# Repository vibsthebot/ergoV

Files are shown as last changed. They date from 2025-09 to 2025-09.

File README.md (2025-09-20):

# ergoV

Picture of Keyboard in Case

A custom ergonomic split keyboard powered by a nrf52840 and PG1316S switches. At under 8 millimeters thick, this keyboard is extremly thin and portable. 

## Features
* Battery Charging
* USB C
* Bluetooth

## PCB 
Image of PCB

## Schematic
Schematic Picture

Designed in [KiCAD](https://kicanvas.org/?github=https%3A%2F%2Fgithub.com%2Fvibsthebot%2FergoV%2Ftree%2Fmain%2Fsrc%2Fleft) and [Onshape](https://cad.onshape.com/documents/23d341e5ba1096076f5e498a/w/17b9fcd4bdbd13d07aada607/e/fd0f7eacd049861961437f33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)

## BOM

| Item | Quantity | Link | Price (each) |
|---|---|---|---|
| 301540 batteries | 2 | [AliExpress](https://www.aliexpress.com/i/2255800173650652.html) | $6.10 |
| PCB (JLCPCB) | 2 | - | $8.40 |
| LCSC parts | - | - | $50.00 |
| PG1316S switches (10 pack) | 4 packs  | [HolyKeebs](https://holykeebs.com/products/kailh-pg1316s-butterfly-switch-10-pack) | $7.50 |
| PG1316S keycaps (10 pack) | 4 packs  | [HolyKeebs](https://holykeebs.com/products/kailh-pg1316s-keycaps) | $4.50 |
| **Total** | | | **$129.60**  |

**Total estimated cost:** $129.60

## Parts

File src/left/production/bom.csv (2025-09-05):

Designator | Footprint | Quantity | Value | LCSC Part #
BT1 | JST_PH_S2B-PH-K_1x02_P2.00mm_Horizontal | 1 | Battery | C265016
C1, C22 | 0402 | 2 | 4.7uF | C1779
C11, C2, C3, C4 | 0402 | 4 | 10uF | C15525
D1, D10, D11, D12, D13, D14, D15, D16, D17, D18, D2, D25, D26, D27, D3, D4, D5, D6, D7, D8, D9 | Diode_SOD-123 | 21 | D | C81598
D28 | D_SOD-123 | 1 | MBR0540 | C77337
D29 | 0805 | 1 | Orange | C434437
J1 | USB_C_Receptacle_G-Switch_GT-USB-7010ASV | 1 | USB_C_Receptacle_USB2.0_16P | C67380
Q1 | SOT-23 | 1 | AO3401A | C306862
R1, R2 | 0402 | 2 | 27 | C25100
R11 | 0402 | 1 | 2k | C17604
R12 | 0402 | 1 | 0.47k | C17710
R3, R4 | 0402 | 2 | 5k1 | C25905
R7 | 0402 | 1 | 10k | C17414
SW1, SW10, SW11, SW12, SW13, SW14, SW15, SW16, SW17, SW18, SW2, SW25, SW26, SW27, SW3, SW4, SW5, SW6, SW7, SW8, SW9 | CPG1316S01D02_kailhspecsheet_mikefive | 21 | SW_Push_3pin_GND
U1 | Raytac_MDBT50Q | 1 | MDBT50Q-1MV2
U2 | SOT-23-5 | 1 | MCP73831-2-OT | C14879
U4 | SOT-23-6 | 1 | USBLC6-2SC6 | C5180249

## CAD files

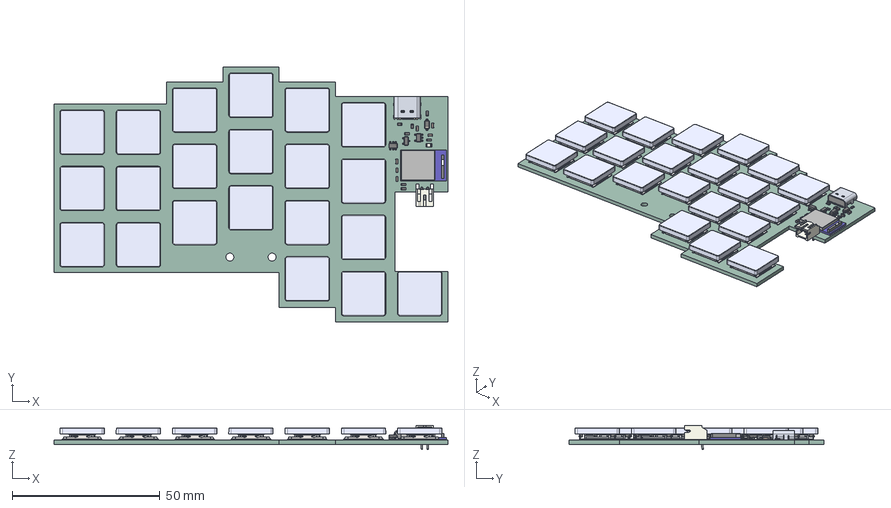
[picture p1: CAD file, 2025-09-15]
src/left/ergoV.step
133.4 x 86.2 x 8.25 mm
Diode_SOD-123 x 21
1316S-»ù×ù¿¨¼þ x 21
PG1316S-»ù×ù x 21
Ƚ¶¯¸ x 21
ƽº⽜ x 21
-» x 21
PG1316S-¶¯½Ó´¥Æ¬-´ø´¥µã x 21
PG1316S-¾²Æ¬-´ø´¥µã x 21
ƽº⽜-B x 21
¼üÃ± x 21
C_0603_1608Metric x 6
USB Type C Port (SMD Type)
R_0603_1608Metric x 7
JST_PH_S2B-PH-K_1x02_P2.00mm_Horizontal
SOT-23-5
D_SOD-123
Raytac_MDBT50Q
SOT-23-6
SOT-23
LED_0805_2012Metric
ergoV_PCB

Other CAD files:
src/right/ergoVright.step

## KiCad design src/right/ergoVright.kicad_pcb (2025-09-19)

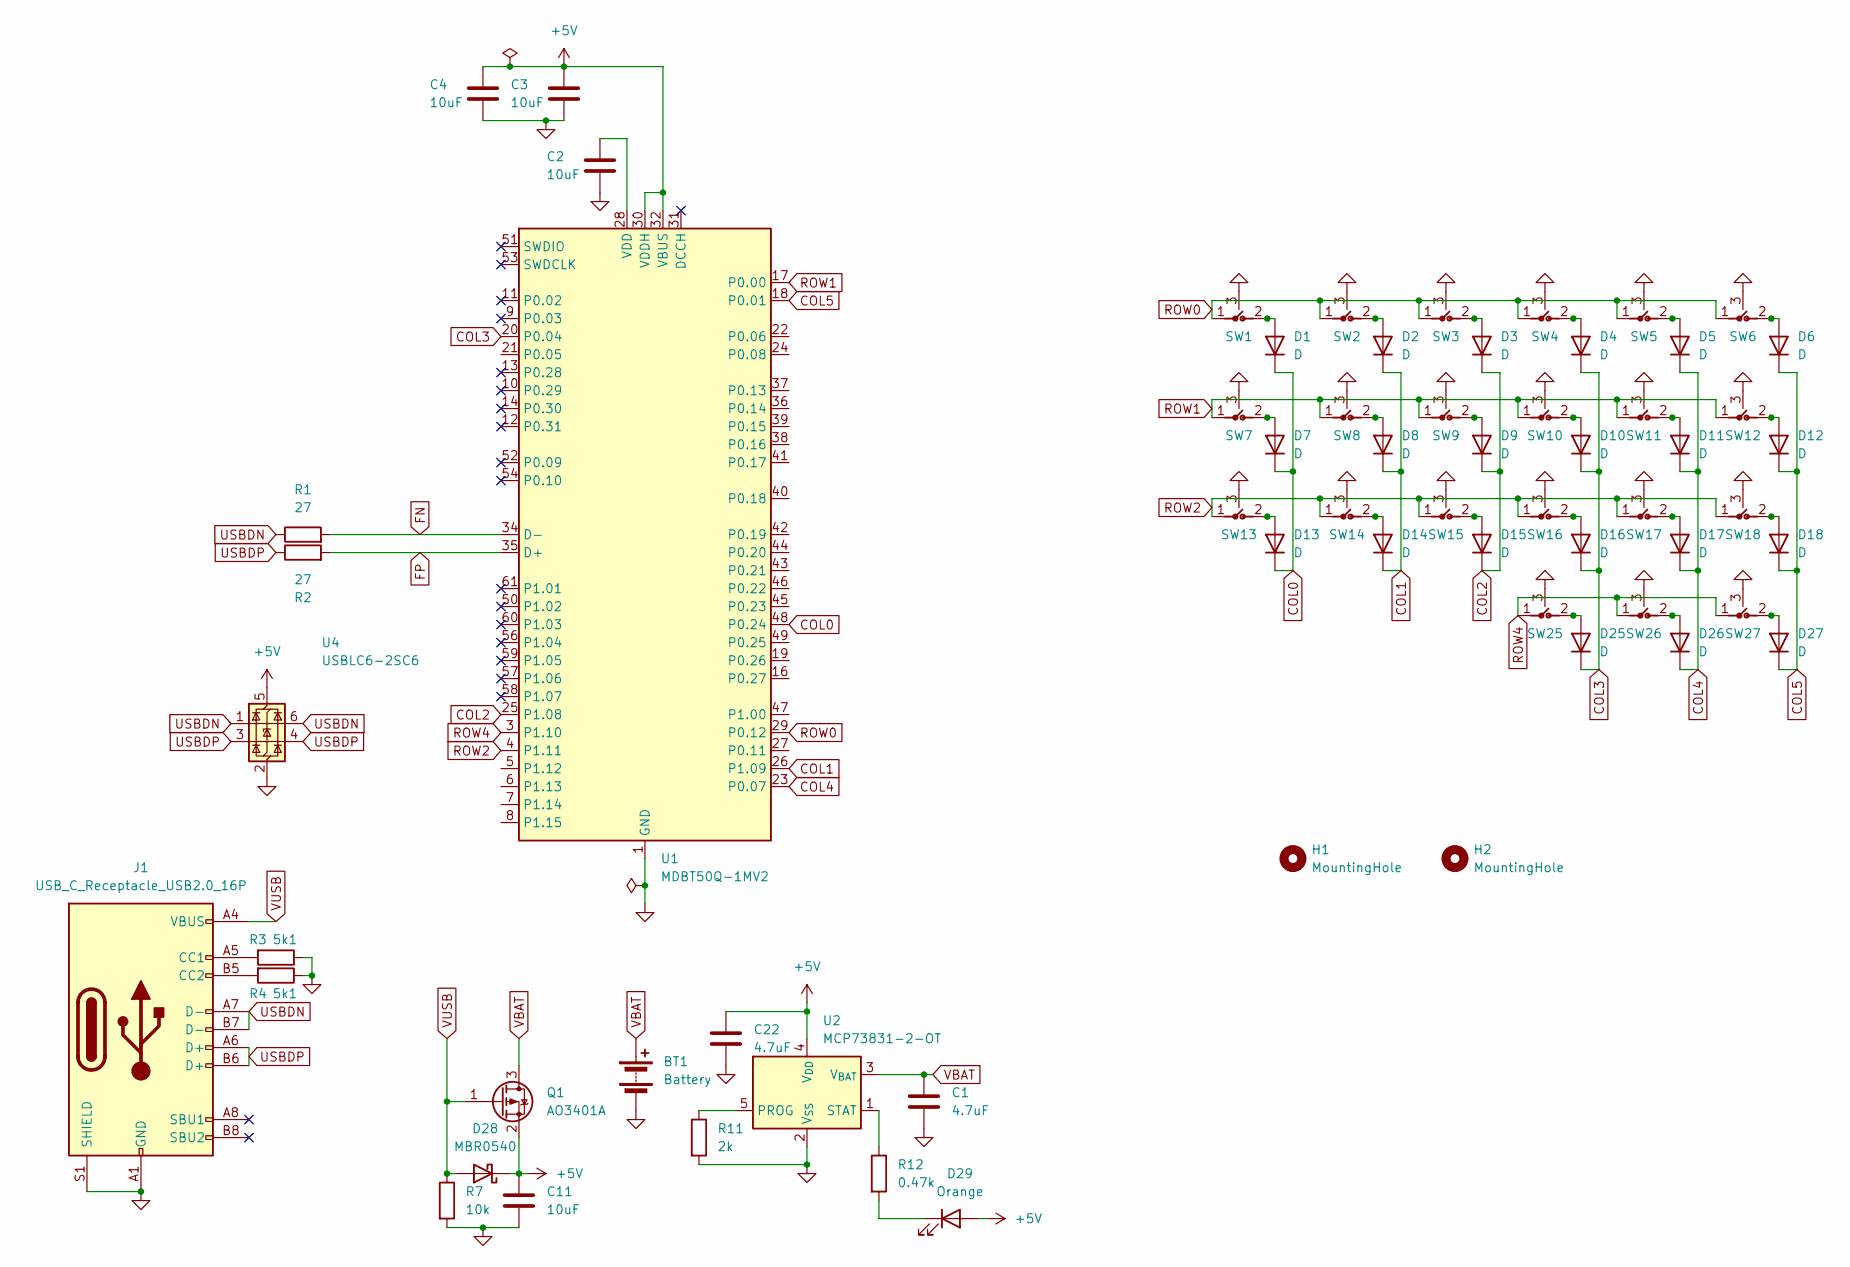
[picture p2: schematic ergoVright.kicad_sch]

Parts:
BT1: Battery; JST_PH_S2B-PH-K_1x02_P2.00mm_Horizontal
C1, C22: 4.7uF; C_0603_1608Metric; LCSC C19666
C2, C3, C4, C11: 10uF; C_0603_1608Metric; LCSC C19702
D1, D2, D3, D4, D5, D6, D7, D8, D9, D10, D11, D12, D13, D14, D15, D16, D17, D18, D25, D26, D27: D; Diode_SOD-123; LCSC C81598
D28: MBR0540; D_SOD-123; LCSC C77337
D29: Orange; LED_0805_2012Metric; LCSC C434437
H1, H2: MountingHole; MountingHole_2.7mm_M2.5
J1: USB_C_Receptacle_USB2.0_16P; USB_C_Receptacle_G-Switch_GT-USB-7010ASV; LCSC C67380
Q1: AO3401A; SOT-23; LCSC C306862
R1, R2: 27; R_0402_1005Metric; LCSC C25100
R3, R4: 5k1; R_0603_1608Metric; LCSC C23186
R7: 10k; R_0603_1608Metric; LCSC C25804
R11: 2k; R_0603_1608Metric; LCSC C22975
R12: 0.47k; R_0603_1608Metric; LCSC C23179
SW1, SW2, SW3, SW4, SW5, SW6, SW7, SW8, SW9, SW10, SW11, SW12, SW13, SW14, SW15, SW16, SW17, SW18, SW25, SW26, SW27: SW_Push_3pin_GND; CPG1316S01D02_kailhspecsheet_mikefive
U1: MDBT50Q-1MV2; Raytac_MDBT50Q; LCSC C14879
U2: MCP73831-2-OT; SOT-23-5; LCSC C5180249
U4: USBLC6-2SC6; SOT-23-6; LCSC C67380

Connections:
+5V: C3.1, C4.1, C11.1, C22.1, D28.1 (K), D29.2 (A), Q1.2 (S), U1.30 (VDDH), U1.32 (VBUS), U2.4 (V_{DD}), U4.5 (VBUS)
COL0: D1.1 (K), D7.1 (K), D13.1 (K), U1.48 (P0.24)
COL1: D2.1 (K), D8.1 (K), D14.1 (K), U1.26 (P1.09)
COL2: D3.1 (K), D9.1 (K), D15.1 (K), U1.25 (P1.08)
COL3: D4.1 (K), D10.1 (K), D16.1 (K), D25.1 (K), U1.20 (P0.04)
COL4: D5.1 (K), D11.1 (K), D17.1 (K), D26.1 (K), U1.23 (P0.07)
COL5: D6.1 (K), D12.1 (K), D18.1 (K), D27.1 (K), U1.18 (P0.01)
FN: R1.2, U1.34 (D-)
FP: R2.2, U1.35 (D+)
GND: BT1.2 (-), C1.2, C2.2, C3.2, C4.2, C11.2, C22.2, J1.A1 (GND), J1.A12 (GND), J1.B1 (GND), J1.B12 (GND), J1.S1 (SHIELD), R3.1, R4.1, R7.2, R11.2, SW1.3, SW2.3, SW3.3, SW4.3, SW5.3, SW6.3, SW7.3, SW8.3, SW9.3, SW10.3, SW11.3, SW12.3, SW13.3, SW14.3, SW15.3, SW16.3, SW17.3, SW18.3, SW25.3, SW26.3, SW27.3, U1.1 (GND), U1.2 (GND), U1.15 (GND), U1.33 (GND), U1.55 (GND), U2.2 (V_{SS}), U4.2 (GND)
unnamed: D1.2 (A), SW1.2
unnamed: D2.2 (A), SW2.2
unnamed: D3.2 (A), SW3.2
unnamed: D4.2 (A), SW4.2
unnamed: D5.2 (A), SW5.2
unnamed: D6.2 (A), SW6.2
unnamed: D7.2 (A), SW7.2
unnamed: D8.2 (A), SW8.2
unnamed: D9.2 (A), SW9.2
unnamed: D10.2 (A), SW10.2
unnamed: D11.2 (A), SW11.2
unnamed: D12.2 (A), SW12.2
unnamed: D13.2 (A), SW13.2
unnamed: D14.2 (A), SW14.2
unnamed: D15.2 (A), SW15.2
unnamed: D16.2 (A), SW16.2
unnamed: D17.2 (A), SW17.2
unnamed: D18.2 (A), SW18.2
unnamed: D25.2 (A), SW25.2
unnamed: D26.2 (A), SW26.2
unnamed: D27.2 (A), SW27.2
unnamed: D29.1 (K), R12.2
unnamed: J1.A5 (CC1), R3.2
unnamed: J1.B5 (CC2), R4.2
unnamed: C2.1, U1.28 (VDD)
unnamed: R11.1, U2.5 (PROG)
unnamed: R12.1, U2.1 (STAT)
ROW0: SW1.1, SW2.1, SW3.1, SW4.1, SW5.1, SW6.1, U1.29 (P0.12)
ROW1: SW7.1, SW8.1, SW9.1, SW10.1, SW11.1, SW12.1, U1.17 (P0.00)
ROW2: SW13.1, SW14.1, SW15.1, SW16.1, SW17.1, SW18.1, U1.4 (P1.11)
ROW4: SW25.1, SW26.1, SW27.1, U1.3 (P1.10)
USBDN: J1.A7 (D-), J1.B7 (D-), R1.1, U4.1 (I/O1), U4.6 (I/O1)
USBDP: J1.A6 (D+), J1.B6 (D+), R2.1, U4.3 (I/O2), U4.4 (I/O2)
VBAT: BT1.1 (+), C1.1, Q1.3 (D), U2.3 (V_{BAT})
VUSB: D28.2 (A), J1.A4 (VBUS), J1.A9 (VBUS), J1.B4 (VBUS), J1.B9 (VBUS), Q1.1 (G), R7.1

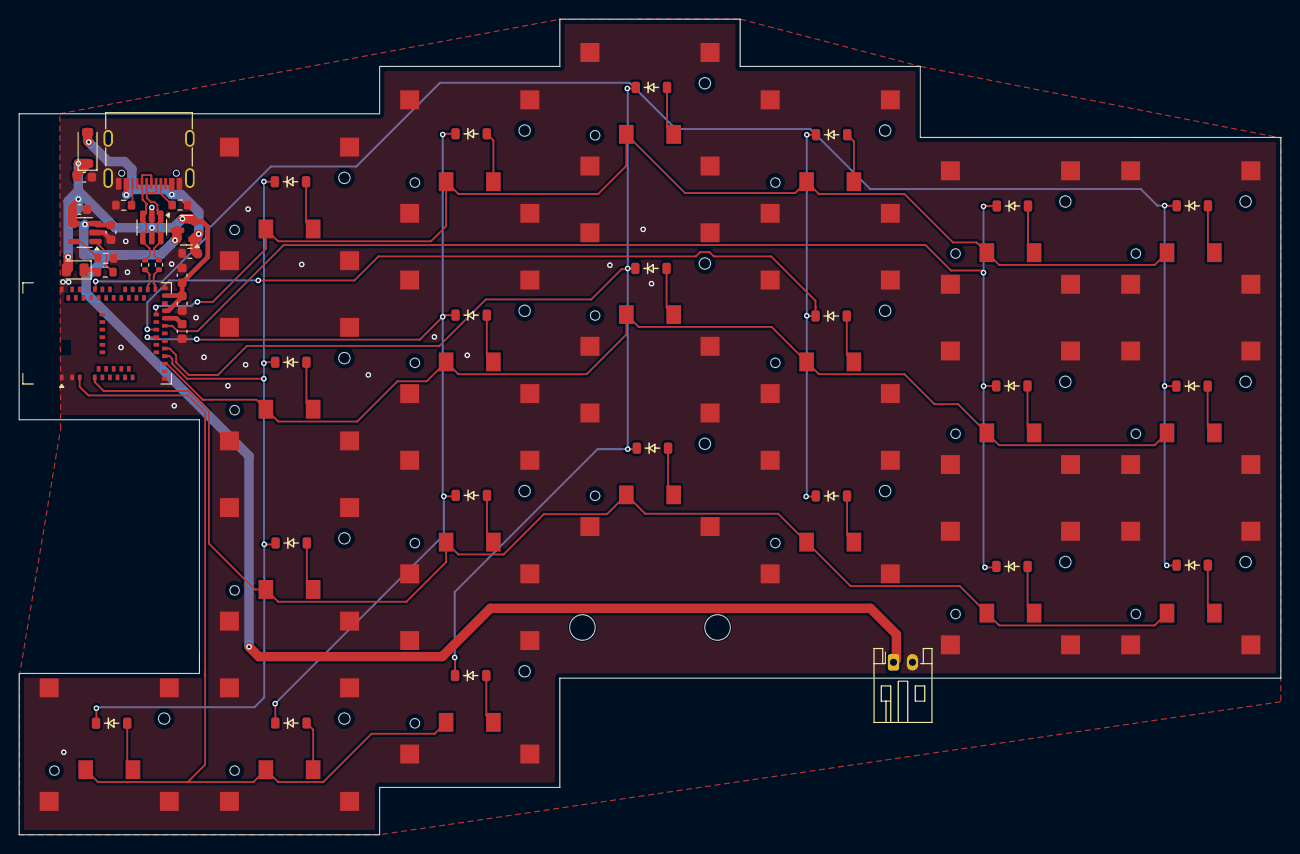
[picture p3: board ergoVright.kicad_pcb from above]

Board: 2 copper layers, 133.4 x 86.2 mm, 65 parts (0 on the bottom side), 45 nets.

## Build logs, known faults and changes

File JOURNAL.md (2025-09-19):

---
Title: "ergoV"
Author: "Vibhu Siddha"
Description: "An ultrathin split mechanical keyboard"
Created On: "8/4/2025"
---

# September 17th (3 hours)
Polished the case, worked on readme. Moved battery to a better location.
Finished Case

# September 12th (4 hours)
Finished most of the case
Case

# September 5th (3.25 hours)
Changed the circuitry to use 0603 components so its easier to solder. I also removed one row from the PCB
Third PCB

# August 29th (4 hours)
Finished routing the thumb area and power ciruitry
Second PCB

# August 27th (4.5 hours)
Finished (most) of the left side layout and routing, I still need to do the schematic for the thumb area and the battery charging + power circuitry
First PCB

# August 25th (3.5 hours)
Finished most of the schematic for the Raytac MCU and the switch array.
Schematic

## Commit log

2025-09-05 Finished keyboard!
    [bom.csv, designators.csv, ergoV.kicad_pcb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]
2025-09-15 Finished pcb, started working on readme
    [ergoV.kicad_pcb, ergoV.kicad_sch, ergoV.step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]
2025-09-19 Finished readme and updated the pcb
    [ergoV.kicad_pcb, ergoV.kicad_sch, ergoVright.kicad_pcb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]
2025-09-20 Added cad
